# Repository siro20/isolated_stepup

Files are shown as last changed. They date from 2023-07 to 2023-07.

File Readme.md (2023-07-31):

# Isolated 12VDC to 300VDC SMPS

This project is about finding a power supply to drive regular 240VAC/120VAC
LED bulbs from a 12V power supply or 12V battery.

This is the first prototype build using the [LTC3723](https://www.analog.com/media/en/technical-documentation/data-sheets/372312f.pdf).

It features:
- Up to 32 Watts
- LC input filter
- Soft-start
- 3 Amps input current limit
- Galvanic isolation
- Adjustable output voltage (for development only)

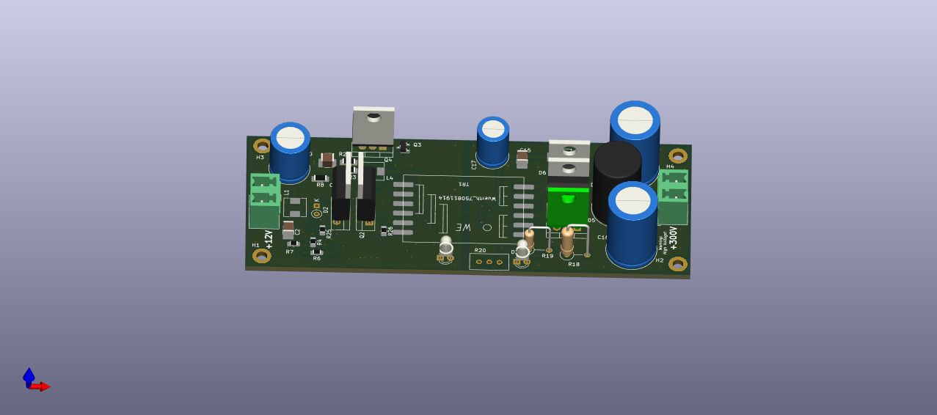
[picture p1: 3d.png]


## Analysis

Measured results of version `0.2`.
- [soft-start](doc/softstart.md)

## Schematics



## Safety advice

    Design, installation and inspection of machinery and devices carrying high voltage
    require accordingly trained and qualified personnel.
    Appropriate safety rules and directives must be complied with.
    Improper handling of high voltage can mean severe injuries or death and may cause
    serious collateral damage! 

## Disclaimer

    THE OPEN SOURCE SOFTWARE/HARDWARE IN THIS PROJECT IS DISTRIBUTED
    IN THE HOPE THAT IT WILL BE USEFUL, BUT WITHOUT ANY WARRANTY, WITHOUT
    EVEN THE IMPLIED WARRANTY OF MERCHANTABILITY OR FITNESS FOR A
    PARTICULAR PURPOSE.

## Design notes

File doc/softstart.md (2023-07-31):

# Soft-start

The soft-start mechanism slowly charges the secondary side capacitor until
it reaches the intended output voltage. This is mandatory as the transformer
only operates within it's expected boundaries when the output caps are
fully charged.

The soft-start capacitor `C12` is slowly charged by the LTC3723. The voltage
accross the softstart capacitor determines the duty-cycle and thus is low at
startup.

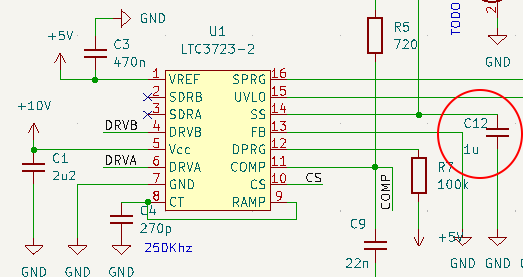
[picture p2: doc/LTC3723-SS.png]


As the secondary side voltage is 0V at startup the transformer sees a short
circuit on the output and the only active inductance is the leakage inductance.

To limit the current on start-up a seconday mechanism was used in addition to
the lower duty-cycles. Two resistors, `R4` and `R24`, were used to limit the
primary side current under heavy load conditions.

Those resistors are bridged by the PMOS `Q4` once the softstart voltage has
reached it's final level:

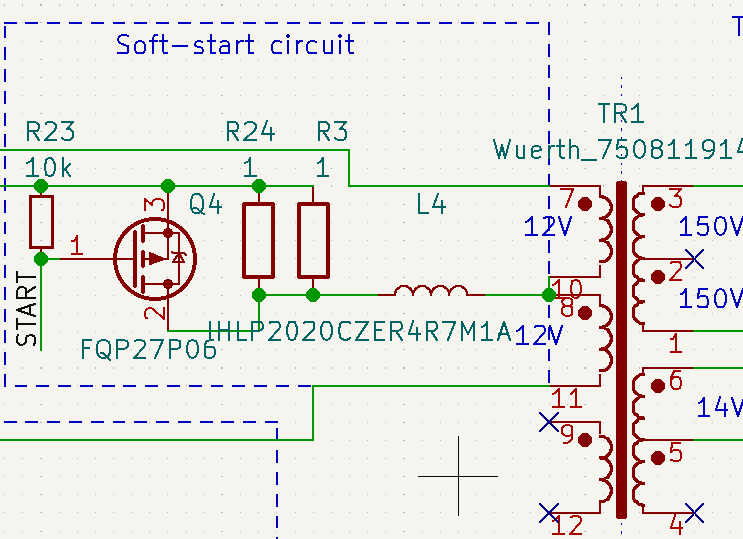
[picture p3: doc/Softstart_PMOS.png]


The soft-start capacitor is slowly charged until it reaches 5V.

## 1uF soft-start capacitor:
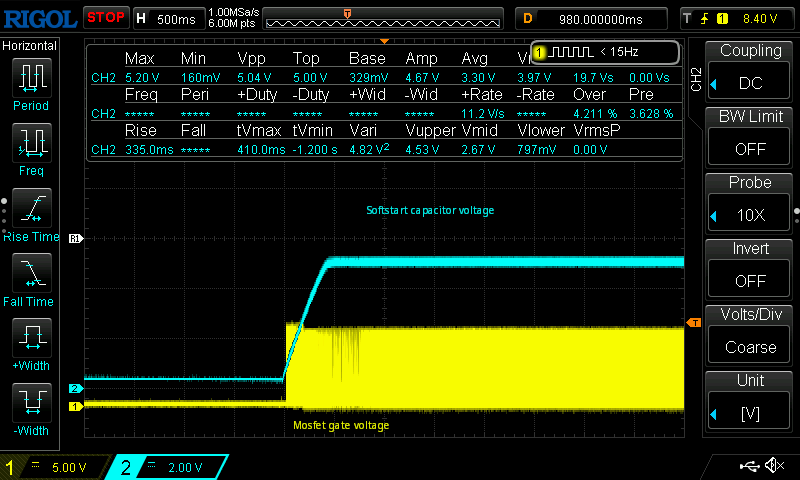
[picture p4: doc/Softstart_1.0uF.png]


**Results**

Soft-start ramp time: 335 msec
Soft-start low level: 330mV
Soft-start high level: 5000mV

## 6.8uF soft-start capacitor:
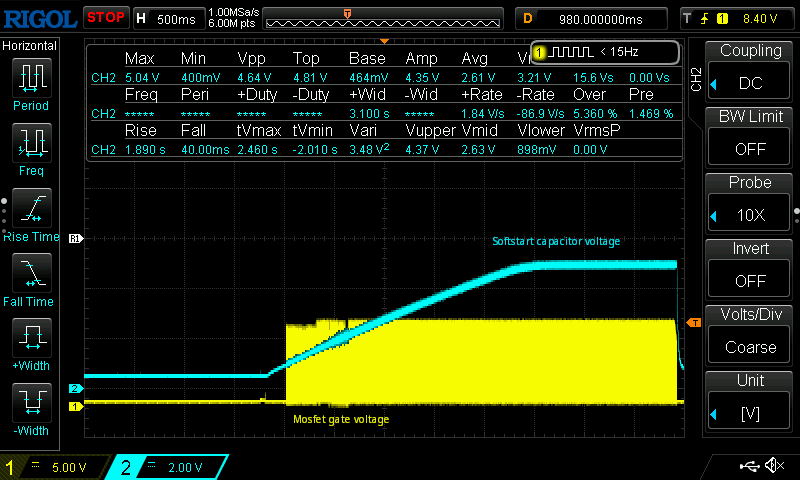
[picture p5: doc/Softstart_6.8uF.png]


**Results**

Soft-start ramp time: 1900 msec
Soft-start low level: 460mV
Soft-start high level: 48000mV

## soft-start switching start

The LTC3723 starts switching after the soft-start voltage has reached a specific
level. Here it is 680mV before it start's switching:

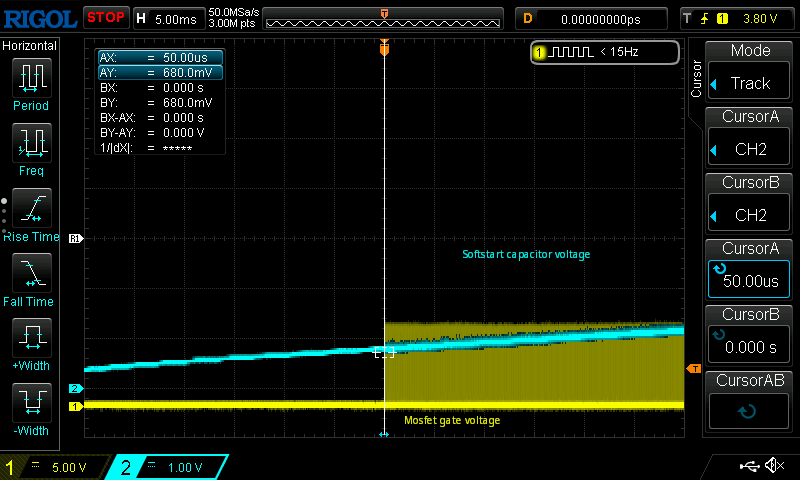
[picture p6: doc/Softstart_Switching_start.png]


This behaviour can be explained by looking at the LTC3723-2 internals. It adds
650mV to the RAMP signal, thus the SS voltage must be more than 650mV to generate
a duty cycle > 0.

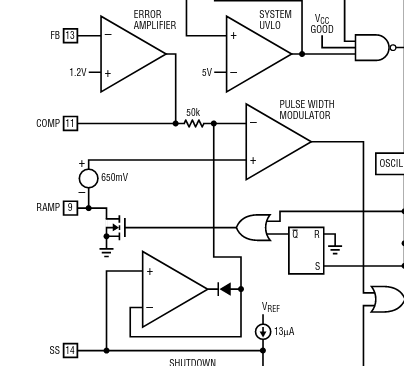
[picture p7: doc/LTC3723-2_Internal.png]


## soft-start vs output voltage

**When there's no load connected at the secondary side:**

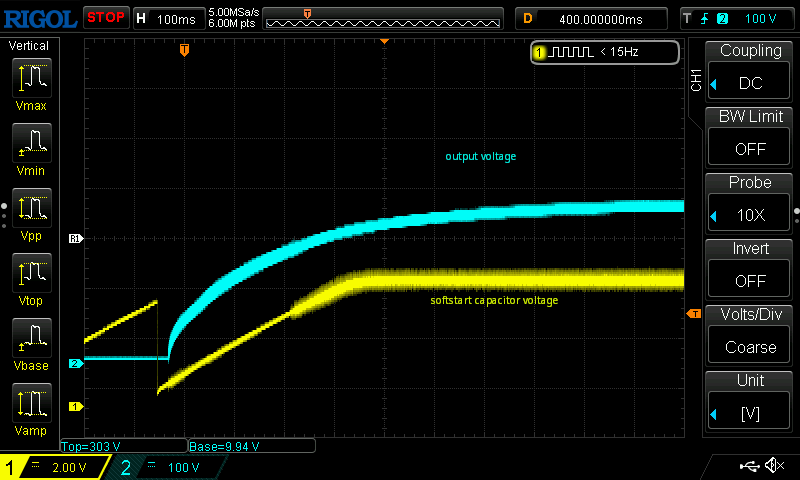
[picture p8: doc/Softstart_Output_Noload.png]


It takes about 900msec to fully charge the secondary side.

**When there's a "9W LED bulb" connected at the secondary side output:**

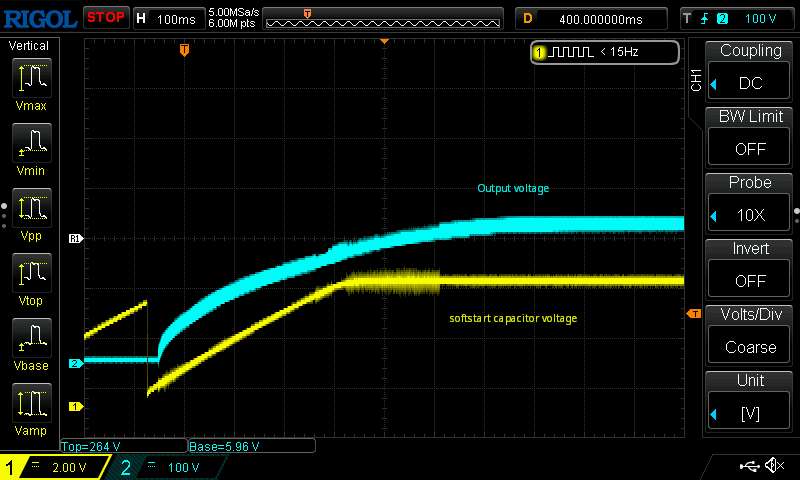
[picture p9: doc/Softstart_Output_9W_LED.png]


It takes about 700msec to fully charge the secondary side.

*TODO: Improve soft-start and charge secondary side faster if possible.*

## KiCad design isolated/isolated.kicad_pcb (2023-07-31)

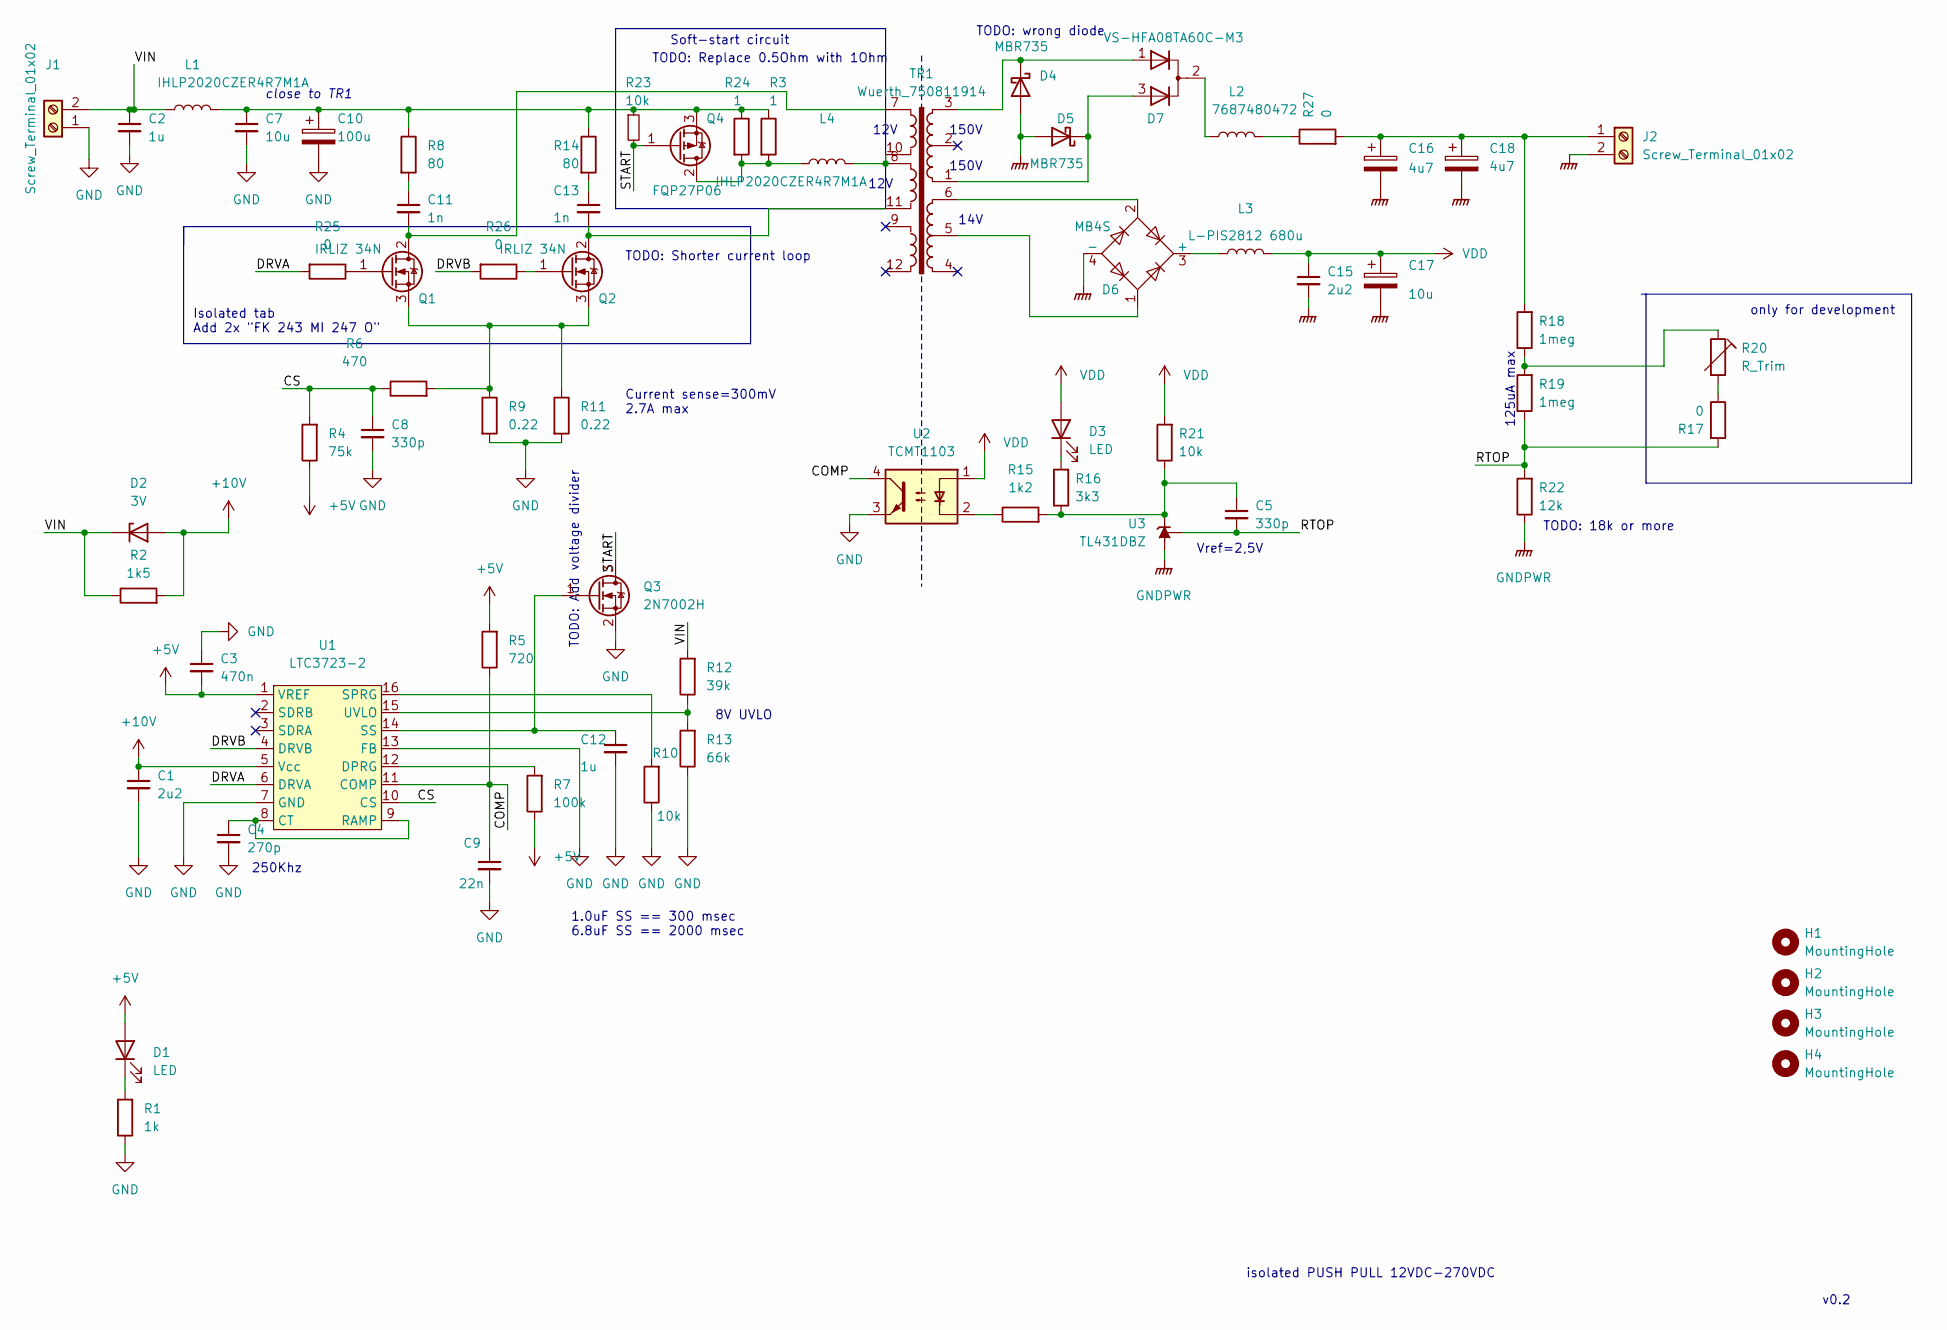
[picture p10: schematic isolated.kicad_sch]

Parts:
C1, C15: 2u2; C_1210_3225Metric_Pad1.33x2.70mm_HandSolder
C2, C12: 1u; C_1210_3225Metric_Pad1.33x2.70mm_HandSolder
C3: 470n; C_0805_2012Metric_Pad1.18x1.45mm_HandSolder
C4: 270p; C_0603_1608Metric_Pad1.08x0.95mm_HandSolder
C5, C8: 330p; C_0603_1608Metric_Pad1.08x0.95mm_HandSolder
C7: 10u; C_1210_3225Metric_Pad1.33x2.70mm_HandSolder
C9: 22n; C_0603_1608Metric_Pad1.08x0.95mm_HandSolder
C10: 100u; C_Radial_D10.0mm_H12.5mm_P5.00mm
C11, C13: 1n; C_0805_2012Metric_Pad1.18x1.45mm_HandSolder
C16, C18: 4u7; C_Radial_D12.5mm_H20.0mm_P5.00mm
C17: 10u; C_Radial_D8.0mm_H11.5mm_P3.50mm
D1, D3: LED; LED_D3.0mm_Clear
D2: 3V; D_DO-34_SOD68_P2.54mm_Vertical_KathodeUp
D4, D5: MBR735; TO-220-2_Vertical
D6: MB4S; TO-269AA
D7: VS-HFA08TA60C-M3; TO-220-3_Vertical
H1, H2, H3, H4: MountingHole; MountingHole_2.7mm_M2.5_DIN965_Pad
J1, J2: Screw_Terminal_01x02; PhoenixContact_MCV_1,5_2-G-5.08_1x02_P5.08mm_Vertical
L1, L4: IHLP2020CZER4R7M1A; L_Sunlord_MWSA05xxS
L2: 7687480472; L_Radial_D12.0mm_P5.00mm_Neosid_SD12_style2
L3: L-PIS2812 680u; L_Vishay_IHLP-2020
Q1, Q2: IRLIZ 34N; TO-220-3_Vertical
Q3: 2N7002H; SOT-23
Q4: FQP27P06; TO-220-3_Vertical
R1: 1k; R_0805_2012Metric_Pad1.20x1.40mm_HandSolder
R2: 1k5; R_0805_2012Metric_Pad1.20x1.40mm_HandSolder
R3, R24: 1; R_1206_3216Metric_Pad1.30x1.75mm_HandSolder
R4: 75k; R_0805_2012Metric_Pad1.20x1.40mm_HandSolder
R5: 720; R_0805_2012Metric_Pad1.20x1.40mm_HandSolder
R6: 470; R_0805_2012Metric_Pad1.20x1.40mm_HandSolder
R7: 100k; R_0805_2012Metric_Pad1.20x1.40mm_HandSolder
R8, R14: 80; R_1206_3216Metric_Pad1.30x1.75mm_HandSolder
R9, R11: 0.22; R_2512_6332Metric_Pad1.40x3.35mm_HandSolder
R10, R21, R23: 10k; R_0805_2012Metric_Pad1.20x1.40mm_HandSolder
R12: 39k; R_0805_2012Metric_Pad1.20x1.40mm_HandSolder
R13: 66k; R_0805_2012Metric_Pad1.20x1.40mm_HandSolder
R15: 1k2; R_0805_2012Metric_Pad1.20x1.40mm_HandSolder
R16: 3k3; R_0805_2012Metric_Pad1.20x1.40mm_HandSolder
R17: 0; R_0805_2012Metric
R18: 1meg; R_Axial_DIN0309_L9.0mm_D3.2mm_P5.08mm_Vertical
R19: 1meg; R_Axial_DIN0207_L6.3mm_D2.5mm_P5.08mm_Vertical
R20: R_Trim; Potentiometer_Bourns_3386C_Horizontal
R22: 12k; R_0805_2012Metric_Pad1.20x1.40mm_HandSolder
R25, R26: 0; R_0805_2012Metric_Pad1.20x1.40mm_HandSolder
R27: 0; R_1206_3216Metric_Pad1.30x1.75mm_HandSolder
TR1: Wuerth_750811914; 750811914
U1: LTC3723-2; SSOP-16_3.9x4.9mm_P0.635mm
U2: TCMT1103; SOP-4_4.4x2.6mm_P1.27mm
U3: TL431DBZ; SOT-23

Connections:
+5V: C3.2, D1.2 (A), R4.1, R5.2, R7.1, U1.1 (VREF)
+10V: C1.1, D2.2 (A), R2.2, U1.5 (Vcc)
/COMP: C9.1, R5.1, U1.11 (COMP), U2.4
/CS: C8.1, R4.2, R6.1, U1.10 (CS)
/DRVA: R25.2, U1.6 (DRVA)
/DRVB: R26.2, U1.4 (DRVB)
/RTOP: C5.2, R17.2, R19.1, R22.2, U3.2 (REF)
/START: Q3.3 (D), Q4.1 (G), R23.2
/VIN: C2.1, D2.1 (K), J1.2, L1.1, R2.1, R12.2
GND: C1.2, C2.2, C3.1, C4.2, C7.2, C8.2, C9.2, C10.2, C12.2, J1.1, Q3.2 (S), R1.1, R9.2, R10.1, R11.2, R13.1, U1.7 (GND), U1.13 (FB), U2.3
GNDPWR: C15.2, C16.2, C17.2, C18.2, D4.2 (A), D5.2 (A), D6.4 (-), J2.2, R22.1, U3.3 (A)
unnamed: C4.1, U1.8 (CT), U1.9 (RAMP)
unnamed: C5.1, R15.2, R16.1, R21.1, U3.1 (K)
unnamed: C11.1, R8.2
unnamed: C11.2, Q1.2 (D), TR1.7
unnamed: C12.1, Q3.1 (G), U1.14 (SS)
unnamed: C13.1, R14.2
unnamed: C13.2, Q2.2 (D), TR1.11
unnamed: C16.1, C18.1, J2.1, R18.2, R27.2
unnamed: D1.1 (K), R1.2
unnamed: D3.1 (K), R16.2
unnamed: D4.1 (K), D7.1 (K), TR1.3
unnamed: D5.1 (K), D7.3 (K), TR1.1
unnamed: D7.2 (A), L2.1
unnamed: L2.2, R27.1
unnamed: D6.3 (+), L3.1
unnamed: L4.1, Q4.2 (D), R3.2, R24.2
unnamed: L4.2, TR1.8, TR1.10
unnamed: Q1.1 (G), R25.1
unnamed: Q2.1 (G), R26.1
unnamed: Q1.3 (S), Q2.3 (S), R6.2, R9.1, R11.1
unnamed: C7.1, C10.1, L1.2, Q4.3 (S), R3.1, R8.1, R14.1, R23.1, R24.1
unnamed: R7.2, U1.12 (DPRG)
unnamed: R10.2, U1.16 (SPRG)
unnamed: R12.1, R13.2, U1.15 (UVLO)
unnamed: R15.1, U2.2
unnamed: R17.1, R20.2
unnamed: R18.1, R19.2, R20.1
unnamed: D6.1, TR1.5
unnamed: D6.2, TR1.6
VDD: C15.1, C17.1, D3.2 (A), L3.2, R21.2, U2.1

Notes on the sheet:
12V
TODO: 18k or more
Isolated tab Add 2x "FK 243 MI 247 O"
TODO: Add voltage divider
150V
only for development
250Khz
TODO: Shorter current loop
1.0uF SS == 300 msec 6.8uF SS == 2000 msec
Soft-start circuit
Vref=2,5V
8V UVLO
close to TR1
TODO: Replace 0.5Ohm with 1Ohm
v0.2
125uA max
TODO: wrong diode
Current sense=300mV 2.7A max
isolated PUSH PULL 12VDC-270VDC
14V

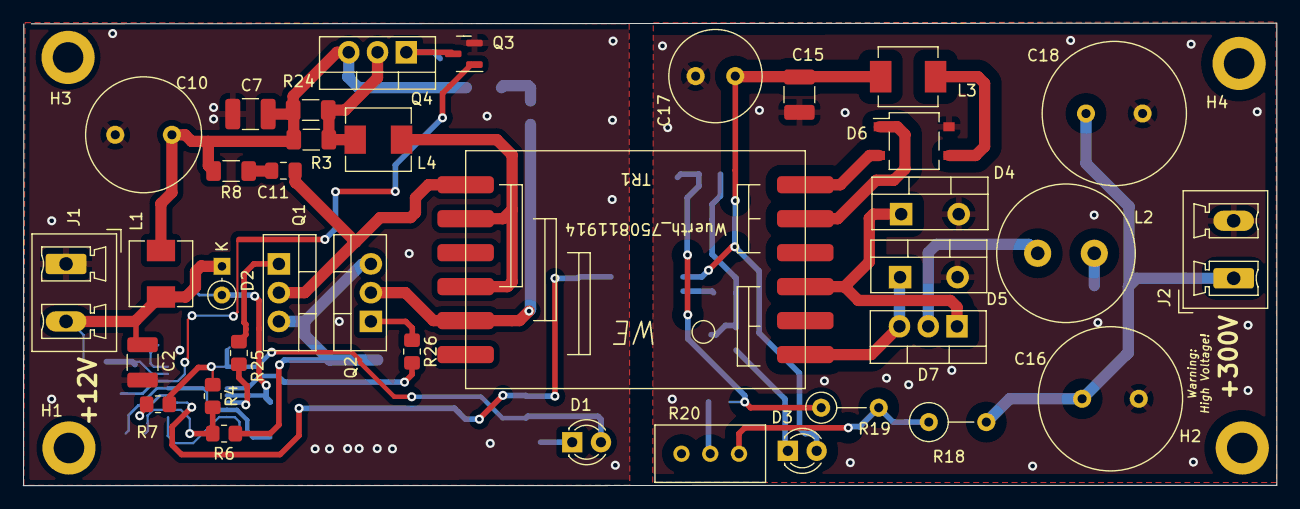
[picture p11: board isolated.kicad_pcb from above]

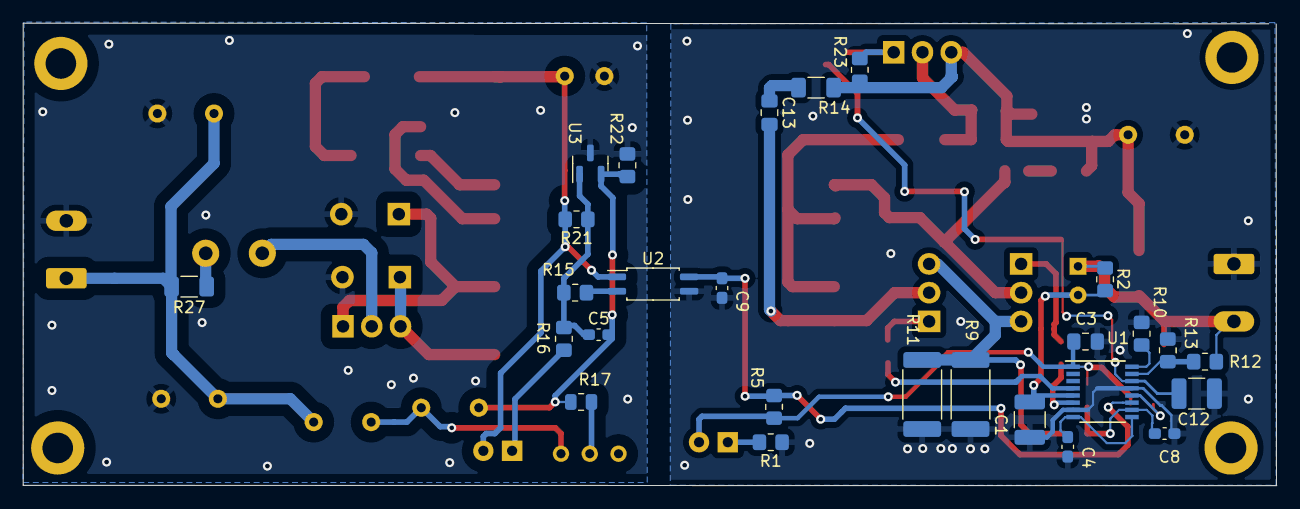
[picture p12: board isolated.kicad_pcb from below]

Board: 2 copper layers, 110.7 x 40.8 mm, 68 parts (27 on the bottom side), 41 nets.

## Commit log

2023-04-10 Initial commit
    - add kicad files
    - add Readme
    - add License
    - add gitignore
    [isolated.kicad_pcb, isolated.kicad_sch]
2023-04-10 Minor fixes
    [isolated.kicad_sch]
2023-04-22 kicad: Minor cleanups
    - Replace LT1431 with TL431.
    [isolated.kicad_pcb, isolated.kicad_sch]
2023-05-10 Readme: Document issues found on the PCB
2023-05-28 kicad: Fix issues found in v0.1
    - Change SOIC to SSOP package
    - Fix MB4S pinout
    [isolated.kicad_pcb, isolated.kicad_sch]
2023-07-31 doc/kicad: Update to revision v0.2
    Fix the problems found in revision v0.1.
    Revision v0.2 works much better and is able to power a
    4W 240VAC LED bulb using 270VDC.
    There are a couple of things to improve though.
    [isolated.kicad_pcb, isolated.kicad_sch]
